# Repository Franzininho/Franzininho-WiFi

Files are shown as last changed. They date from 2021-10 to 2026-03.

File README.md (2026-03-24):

# Franzininho WiFi

The Franzininho WiFi Board is a development board based on the ESP32-S2-WROOM module.

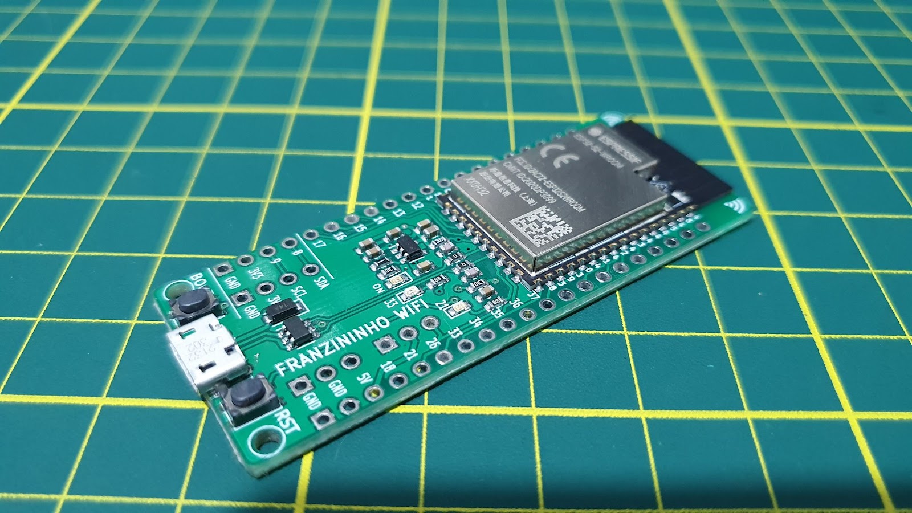
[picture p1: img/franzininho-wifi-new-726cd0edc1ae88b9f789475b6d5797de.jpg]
front


---

## Documentation

For more details, check the official documentation:  
[Franzininho WiFi Documentation](https://docs.franzininho.com.br/docs/franzininho-wifi/franzininho-wifi)

---

## Features

- **ESP32-S2-WROOM Module**
  - Xtensa® single-core 32-bit LX7 microcontroller running at up to 240 MHz
  - Memory:
    - 128 KB ROM
    - 320 KB SRAM
    - 16 KB RTC SRAM
    - 4 MB Flash
  - Wi-Fi 802.11 b/g/n

- **Interfaces**
  - GPIO, SPI, LCD, UART, I2C, I2S
  - Camera, IR, pulse counter, LED PWM
  - TWAI (CAN), USB 1.1 OTG
  - ADC, DAC, touch sensor, internal temperature sensor

- **Pinout**
  - 40 pins arranged in 2x20 headers (2.54 mm pitch)
  - 35 GPIOs available
  - Breadboard compatible

- **LEDs**
  - 2 general-purpose LEDs

- **Buttons**
  - 1 × Reset
  - 1 × Boot

- **USB**
  - Micro USB connector (USB 1.1 OTG)

- **Power Supply**
  - 5V via USB connector
  - 5V and GND via pins
  - 3.3V and GND via pins

- **Programming Support**
  - ESP-IDF
  - Arduino
  - CircuitPython
  - MicroPython

---

## Pinout

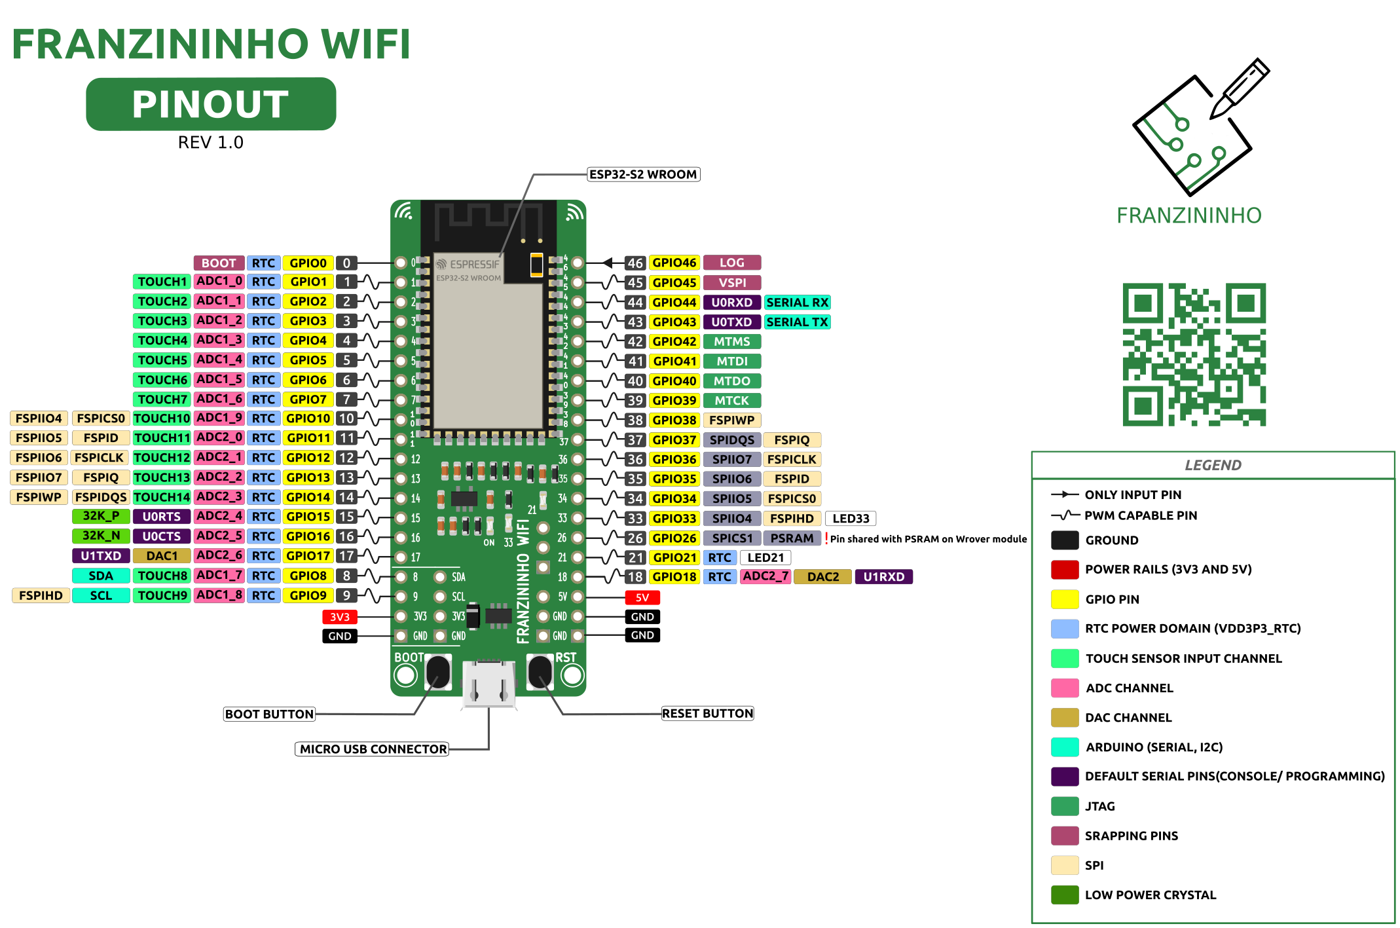
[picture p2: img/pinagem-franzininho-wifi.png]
pinout


## License

This project is open-source hardware and is available under the CERN Open Hardware License.

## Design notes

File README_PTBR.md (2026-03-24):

# Franzininho WiFi

A placa Franzininho WiFi é uma placa de desenvolvimento baseada no módulo ESP32-S2-WROOM.

front

---

## Documentação

Para mais detalhes, acesse a documentação oficial:  
[Documentação Franzininho WiFi](https://docs.franzininho.com.br/docs/franzininho-wifi/franzininho-wifi)

---

## Características

- **Módulo ESP32-S2-WROOM**
  - Microcontrolador Xtensa® single-core 32 bits LX7 operando em até 240 MHz
  - Memória:
    - 128 KB de ROM
    - 320 KB de SRAM
    - 16 KB de SRAM RTC
    - 4 MB de Flash
  - Wi-Fi 802.11 b/g/n

- **Interfaces**
  - GPIO, SPI, LCD, UART, I2C, I2S
  - Câmera, IR, contador de pulsos, LED PWM
  - TWAI (CAN), USB 1.1 OTG
  - ADC, DAC, sensor de toque, sensor de temperatura interno

- **Pinagem**
  - 40 pinos organizados em 2x20 headers (passo de 2,54 mm)
  - 35 GPIOs disponíveis
  - Compatível com protoboard

- **LEDs**
  - 2 LEDs de uso geral

- **Botões**
  - 1 × Reset
  - 1 × Boot

- **USB**
  - Conector Micro USB (USB 1.1 OTG)

- **Alimentação**
  - 5V via conector USB
  - 5V e GND via pinos
  - 3,3V e GND via pinos

- **Suporte de Programação**
  - ESP-IDF
  - Arduino
  - CircuitPython
  - MicroPython

---

## Pinagem

pinout

---

## Licença

Este projeto é um hardware open-source e está disponível sob a licença CERN Open Hardware.

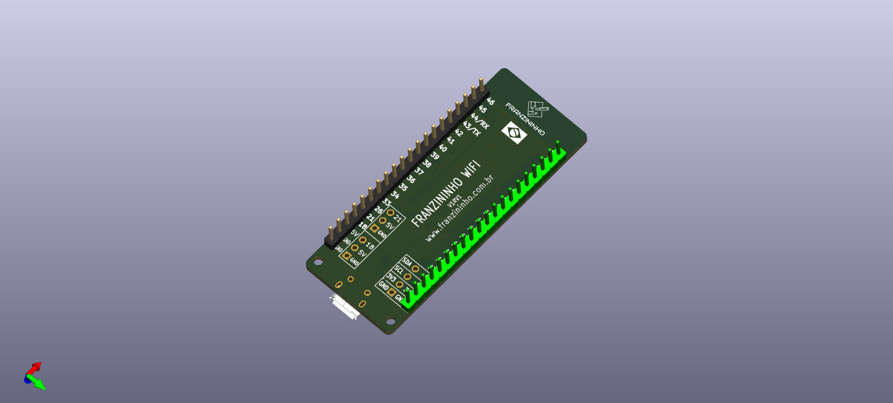
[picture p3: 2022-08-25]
Franzininho-WIFI-kicad/imagens/Franzininho WIFI5.png

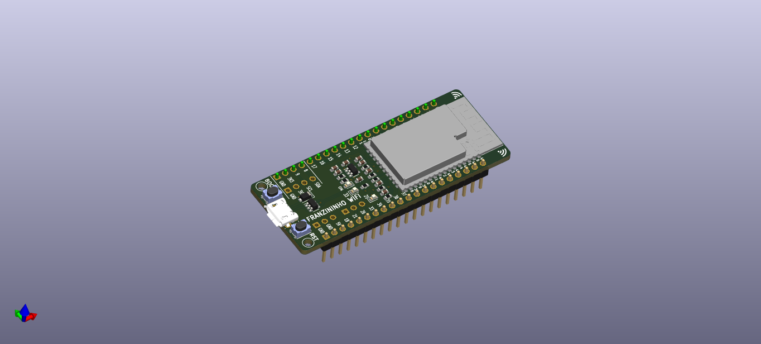
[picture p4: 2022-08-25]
Franzininho-WIFI-kicad/imagens/Franzininho WIFI4.png

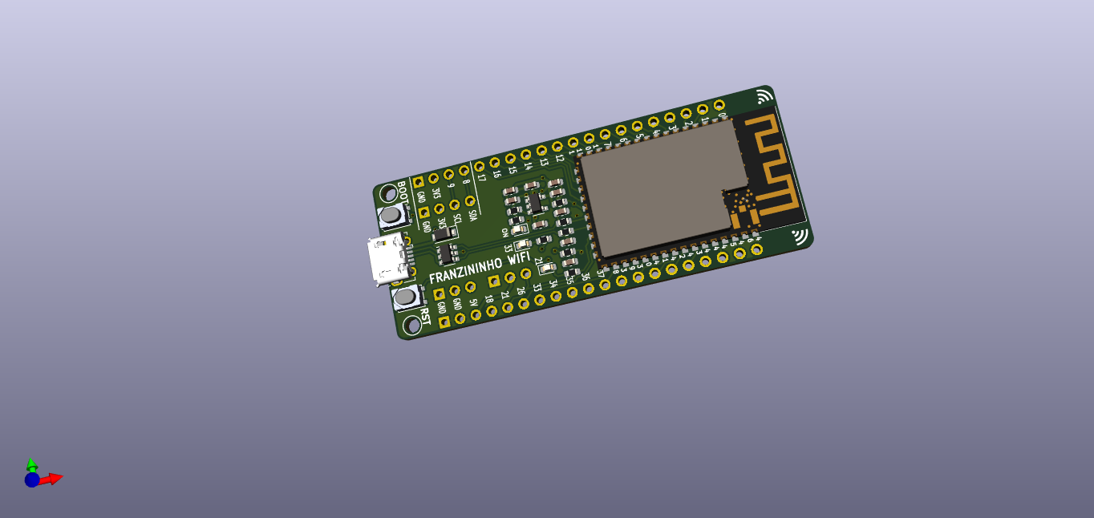
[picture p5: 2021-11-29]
Franzininho-WIFI-kicad/imagens/Franzininho WIFI.png

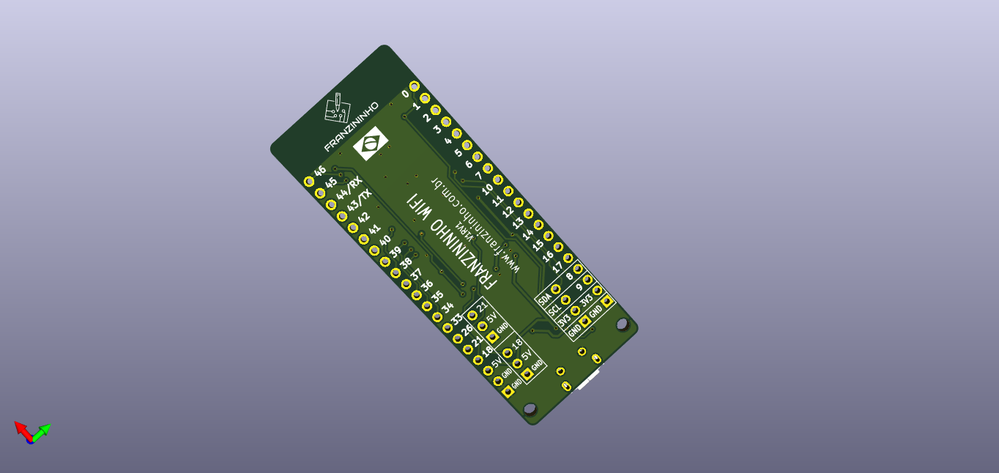
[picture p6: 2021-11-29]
Franzininho-WIFI-kicad/imagens/Franzininho WIFI3.png

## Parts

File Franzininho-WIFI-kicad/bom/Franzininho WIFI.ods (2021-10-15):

Reference | Value | datasheet | LCSC | PN
R3 | 0 | https://datasheet.lcsc.com/lcsc/1810171817_UNI-ROYAL-Uniroyal-Elec-0603WAF0000T5E_C21189.pdf | C21189 | 0603WAF0000T5E | https://lcsc.com/product-detail/Chip-Resistor-Surface-Mount_UNI-ROYAL-Uniroyal-Elec-0603WAF0000T5E_C21189.html
R4 | 0 | https://datasheet.lcsc.com/lcsc/1810171817_UNI-ROYAL-Uniroyal-Elec-0603WAF0000T5E_C21189.pdf | C21189 | 0603WAF0000T5E | https://lcsc.com/product-detail/Chip-Resistor-Surface-Mount_UNI-ROYAL-Uniroyal-Elec-0603WAF0000T5E_C21189.html
R6 | 100k | https://datasheet.lcsc.com/lcsc/1810170813_PANASONIC-ERJPB3D1003V_C189496.pdf | C189496 | ERJPB3D1003V | https://lcsc.com/product-detail/Chip-Resistor-Surface-Mount_PANASONIC-ERJPB3D1003V_C189496.html
C3 | 100nF | https://datasheet.lcsc.com/lcsc/1809301912_YAGEO-CC0603KRX7R9BB104_C14663.pdf | C14663 | CC0603KRX7R9BB104 | https://lcsc.com/product-detail/Multilayer-Ceramic-Capacitors-MLCC-SMD-SMT_YAGEO-CC0603KRX7R9BB104_C14663.html
C9 | 100nF | https://datasheet.lcsc.com/lcsc/1809301912_YAGEO-CC0603KRX7R9BB104_C14663.pdf | C14663 | CC0603KRX7R9BB104 | https://lcsc.com/product-detail/Multilayer-Ceramic-Capacitors-MLCC-SMD-SMT_YAGEO-CC0603KRX7R9BB104_C14663.html
R2 | 10k | https://datasheet.lcsc.com/lcsc/1811062009_UNI-ROYAL-Uniroyal-Elec-0603WAF1002T5E_C25804.pdf | C25804 | 0603WAF1002T5E | https://lcsc.com/product-detail/Chip-Resistor-Surface-Mount_UNI-ROYAL-Uniroyal-Elec-0603WAF1002T5E_C25804.html
R5 | 10k | https://datasheet.lcsc.com/lcsc/1811062009_UNI-ROYAL-Uniroyal-Elec-0603WAF1002T5E_C25804.pdf | C25804 | 0603WAF1002T5E | https://lcsc.com/product-detail/Chip-Resistor-Surface-Mount_UNI-ROYAL-Uniroyal-Elec-0603WAF1002T5E_C25804.html
R1 | 10k | https://datasheet.lcsc.com/lcsc/1811062009_UNI-ROYAL-Uniroyal-Elec-0603WAF1002T5E_C25804.pdf | C25804 | 0603WAF1002T5E | https://lcsc.com/product-detail/Chip-Resistor-Surface-Mount_UNI-ROYAL-Uniroyal-Elec-0603WAF1002T5E_C25804.html
C6 | 10uF | https://datasheet.lcsc.com/lcsc/1810191219_Samsung-Electro-Mechanics-CL10A106KP8NNNC_C19702.pdf | C19702 | CL10A106KP8NNNC | https://lcsc.com/product-detail/Multilayer-Ceramic-Capacitors-MLCC-SMD-SMT_Samsung-Electro-Mechanics-CL10A106KP8NNNC_C19702.html
C7 | 10uF | https://datasheet.lcsc.com/lcsc/1810191219_Samsung-Electro-Mechanics-CL10A106KP8NNNC_C19702.pdf | C19702 | CL10A106KP8NNNC | https://lcsc.com/product-detail/Multilayer-Ceramic-Capacitors-MLCC-SMD-SMT_Samsung-Electro-Mechanics-CL10A106KP8NNNC_C19702.html
C8 | 10uF | https://datasheet.lcsc.com/lcsc/1810191219_Samsung-Electro-Mechanics-CL10A106KP8NNNC_C19702.pdf | C19702 | CL10A106KP8NNNC | https://lcsc.com/product-detail/Multilayer-Ceramic-Capacitors-MLCC-SMD-SMT_Samsung-Electro-Mechanics-CL10A106KP8NNNC_C19702.html
R7 | 470 | https://datasheet.lcsc.com/lcsc/1912111437_PANASONIC-ERJ3GEYJ471V_C169852.pdf | C169852 | ERJ3GEYJ471V | https://lcsc.com/product-detail/Chip-Resistor-Surface-Mount_PANASONIC-ERJ3GEYJ471V_C169852.html
R8 | 1k | https://datasheet.lcsc.com/lcsc/1912111437_PANASONIC-ERJ3GEYJ471V_C169852.pdf | C2758735 | NQ03WAF1001T5E | https://lcsc.com/product-detail/Chip-Resistor-Surface-Mount_UNI-ROYAL-Uniroyal-Elec-NQ03WAF1001T5E_C2758735.html
D1 | 1N5819W | https://datasheet.lcsc.com/lcsc/1811081220_Shandong-Jingdao-Microelectronics-1N5819W_C169540.pdf | C169540 | 1N5819W | https://lcsc.com/product-detail/Schottky-Barrier-Diodes-SBD_Shandong-Jingdao-Microelectronics-1N5819W_C169540.html
C2 | 1uF | https://datasheet.lcsc.com/lcsc/1810261812_Samsung-Electro-Mechanics-CL10A105KB8NNNC_C15849.pdf | C15849 | CL10A105KB8NNNC | https://lcsc.com/product-detail/Multilayer-Ceramic-Capacitors-MLCC-SMD-SMT_Samsung-Electro-Mechanics-CL10A105KB8NNNC_C15849.html
C4 | 20pF | https://datasheet.lcsc.com/lcsc/1810261514_Samsung-Electro-Mechanics-CL10C200JB8NNNC_C1648.pdf | C1648 | CL10C200JB8NNNC | https://lcsc.com/product-detail/Multilayer-Ceramic-Capacitors-MLCC-SMD-SMT_Samsung-Electro-Mechanics-CL10C200JB8NNNC_C1648.html
C5 | 20pF | https://datasheet.lcsc.com/lcsc/1810261514_Samsung-Electro-Mechanics-CL10C200JB8NNNC_C1648.pdf | C1648 | CL10C200JB8NNNC | https://lcsc.com/product-detail/Multilayer-Ceramic-Capacitors-MLCC-SMD-SMT_Samsung-Electro-Mechanics-CL10C200JB8NNNC_C1648.html
C1 | 22uF | https://datasheet.lcsc.com/lcsc/1811151138_Samsung-Electro-Mechanics-CL10A226MQ8NRNC_C59461.pdf | C59461 | CL10A226MQ8NRNC | https://lcsc.com/product-detail/Multilayer-Ceramic-Capacitors-MLCC-SMD-SMT_Samsung-Electro-Mechanics-CL10A226MQ8NRNC_C59461.html
U3 | AP2112K-3.3 | https://www.diodes.com/assets/Datasheets/AP2112.pdf | C51118 | AP2112K-3.3TRG1 | https://lcsc.com/product-detail/Linear-Voltage-Regulators-LDO_Diodes-Incorporated-AP2112K-3-3TRG1_C51118.html
SW2 | BOOT | https://datasheet.lcsc.com/lcsc/1811092141_C-K-PTS810SJM250SMTRLFS_C116501.pdf | C116501 | PTS810SJM250SMTRLFS | https://lcsc.com/product-detail/Tactile-Switches_C-K-PTS810SJM250SMTRLFS_C116501.html
J3 | Conn_01x20_Male | https://datasheet.lcsc.com/lcsc/1810312312_BOOMELE-Boom-Precision-Elec-C50984_C50984.pdf | C50984 | C50984 | https://lcsc.com/product-detail/Female-Headers_BOOMELE-Boom-Precision-Elec-C50984_C50984.html
J2 | Conn_01x20_Male | https://datasheet.lcsc.com/lcsc/1810312312_BOOMELE-Boom-Precision-Elec-C50984_C50984.pdf | C50984 | C50984 | https://lcsc.com/product-detail/Female-Headers_BOOMELE-Boom-Precision-Elec-C50984_C50984.html
U2 | ESP32-S2-WROOM | https://datasheet.lcsc.com/lcsc/2012061534_Espressif-Systems-ESP32-S2-WROOM-4M_C967025.pdf | C967025 | ESP32-S2-WROOM(4M) | https://lcsc.com/product-detail/WiFi-Modules_Espressif-Systems-ESP32-S2-WROOM-4M_C967025.html
D2 | LED | https://datasheet.lcsc.com/lcsc/1811101510_Everlight-Elec-19-217-GHC-YR1S2-3T_C72043.pdf | C72043 | 19-217/GHC-YR1S2/3T | https://lcsc.com/product-detail/Light-Emitting-Diodes-LED_Everlight-Elec-19-217-GHC-YR1S2-3T_C72043.html
D3 | LED | https://datasheet.lcsc.com/lcsc/1811061220_Everlight-Elec-19-217-BHC-XL2M2TY-3T_C264464.pdf | C264464 | 19-217/BHC-XL2M2TY/3T | https://lcsc.com/product-detail/Light-Emitting-Diodes-LED_Everlight-Elec-19-217-BHC-XL2M2TY-3T_C264464.html
D4 | LED | https://datasheet.lcsc.com/lcsc/1810101813_Everlight-Elec-19-213-Y2C-CQ2R2L-3T-CY_C72038.pdf | C72038 | 19-213/Y2C-CQ2R2L/3T(CY) | https://lcsc.com/product-detail/Light-Emitting-Diodes-LED_Everlight-Elec-19-213-Y2C-CQ2R2L-3T-CY_C72038.html
SW1 | RESET | https://datasheet.lcsc.com/lcsc/1811092141_C-K-PTS810SJM250SMTRLFS_C116501.pdf | C116501 | PTS810SJM250SMTRLFS | https://lcsc.com/product-detail/Tactile-Switches_C-K-PTS810SJM250SMTRLFS_C116501.html
J1 | USB_B_Micro | https://datasheet.lcsc.com/lcsc/2004301811_MOLEX-1050171001_C505111.pdf | C505111 | 1050171001 | https://lcsc.com/product-detail/USB-Connectors_MOLEX-1050171001_C505111.html
U1 | USBLC6-2SC6 | https://datasheet.lcsc.com/lcsc/1811141711_STMicroelectronics-USBLC6-2SC6_C7519.pdf | C7519 | USBLC6-2SC6 | https://lcsc.com/product-detail/ESD-Protection-Devices_STMicroelectronics-USBLC6-2SC6_C7519.html

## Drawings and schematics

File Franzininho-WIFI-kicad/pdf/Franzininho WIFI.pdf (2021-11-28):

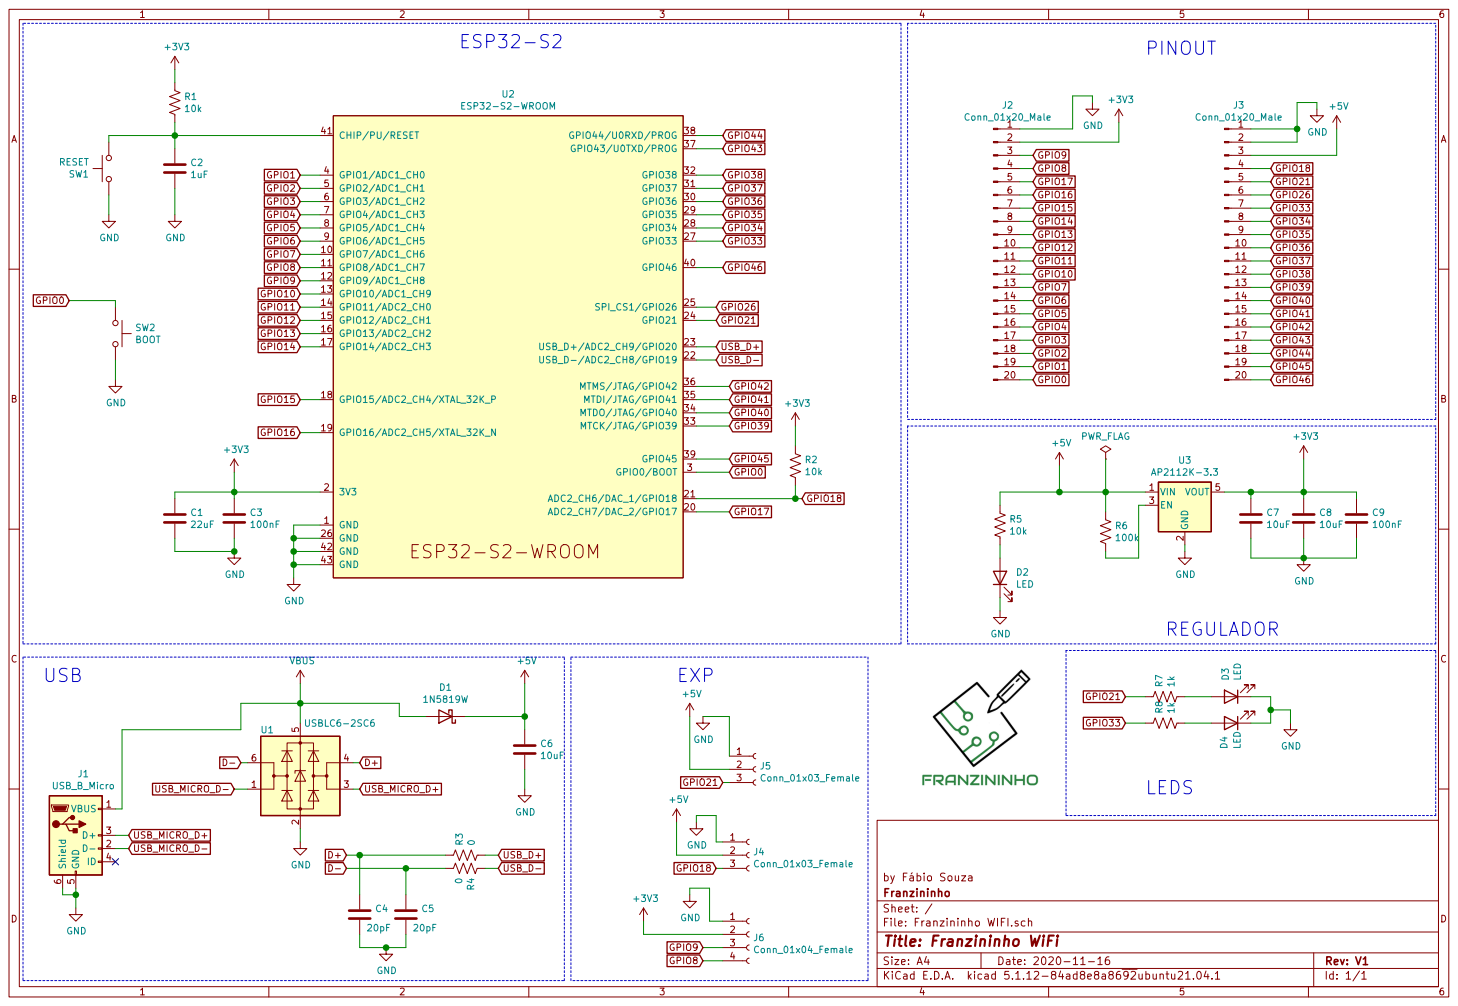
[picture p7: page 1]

by Fábio Souza GND

Id: 1/1 Title: Franzininho WiFi File: Franzininho WIFI.sch Sheet: / Franzininho

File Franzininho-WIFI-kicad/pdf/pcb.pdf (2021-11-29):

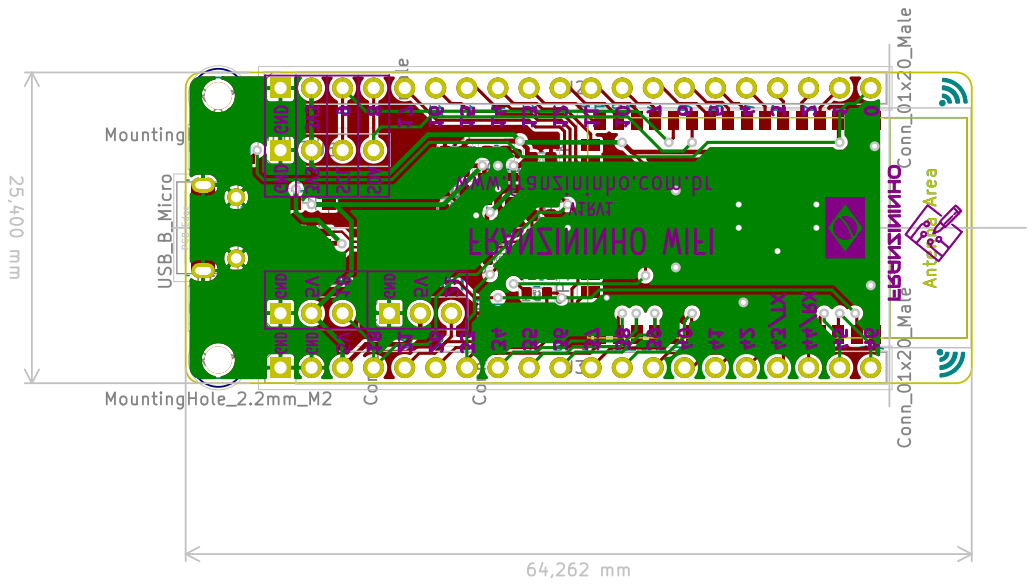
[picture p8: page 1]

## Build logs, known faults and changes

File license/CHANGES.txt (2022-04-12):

Here we are compiling a community changelog.

If you come up with a modification of our designs, please share it with the community, log your changes below, and upload the files to our GitHub repository.

Change Format
Your name Date Description of modification

Change Log

Fabio Souza 2021-11-29 Initial release of Franzininho WIFI under CERN OHL v1.2 or later.

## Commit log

2021-05-30 Adicionando versão inicial da placa
    [Franzininho WIFI.kicad_pcb, Franzininho WIFI.sch]
2021-10-11 Adicionando versão final antes da revisão
    [Franzininho WIFI.kicad_pcb, Franzininho WIFI.sch]
2021-10-12 Ajustes finais
    [Franzininho WIFI.kicad_pcb]
2021-10-15 Adicionando lista de materiais
    [Franzininho WIFI.csv, Franzininho WIFI.ods, Franzininho WIFI.sch]
2021-10-15 Adicionando todos os componentes
    [Franzininho WIFI.csv, Franzininho WIFI.ods]
2021-10-15 Adicionando informações de fabricação
    [Franzininho WIFI-B_Mask.gbs, Franzininho WIFI-B_Paste.gbp, Franzininho WIFI-B_SilkS.gbo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]
2021-10-18 Atualizando pino do LED
    [Franzininho WIFI-B_Mask.gbs, Franzininho WIFI-B_Paste.gbp, Franzininho WIFI-B_SilkS.gbo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]
2021-11-28 Ajuste de thermal reliaf
    [Franzininho WIFI.kicad_pcb, Franzininho WIFI.sch]
2021-11-28 Nova revisão V1RV1
    [Franzininho WIFI-B_Mask.gbs, Franzininho WIFI-B_Paste.gbp, Franzininho WIFI-B_SilkS.gbo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]
2021-11-28 Ajustes na Nova revisão V1RV1
    [Franzininho WIFI-B_Mask.gbs, Franzininho WIFI-B_Paste.gbp, Franzininho WIFI-B_SilkS.gbo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]
2021-11-28 Ajustes na documentação: imagens e PDF
    [Franzininho WIFI.kicad_pcb]
2021-11-29 ajustes de silk e arquivos
    [Franzininho WIFI-B_Mask.gbs, Franzininho WIFI-B_Paste.gbp, Franzininho WIFI-B_SilkS.gbo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]
2022-08-25 Adicionando novos modelos 3D da placa Finalizada
    [Franzininho WIFI.kicad_pcb, Franzininho WIFI.kicad_sch]
2026-03-24 Revise README for Franzininho WiFi Board
    Updated the README.md to improve clarity and organization of features and specifications.
2026-03-24 Add README for Franzininho WiFi board
    Adiciona documentação e características do Franzininho WiFi.
